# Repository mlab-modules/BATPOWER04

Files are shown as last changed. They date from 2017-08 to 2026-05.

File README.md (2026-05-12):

# BATPOWER04 - Step-down Voltage Converter Module

BATPOWER04 is a step-down voltage converter module based on the [LM3485](doc/pdf/lm3485.pdf) PFET buck controller. The input voltage range is 4.5 V to 16 V. The output voltage can be selected by jumpers as 3.3 V or 5 V, or configured as a custom voltage using an external resistor or trimmer. The output voltage range is 0.25 V to Vin.

The module is especially suited for battery-powered applications, but it can also be used as a step-down converter from an external 12 V supply to 3.3 V or 5 V for MLAB designs. Its key feature is high efficiency, up to 93%, which helps reduce waste heat.

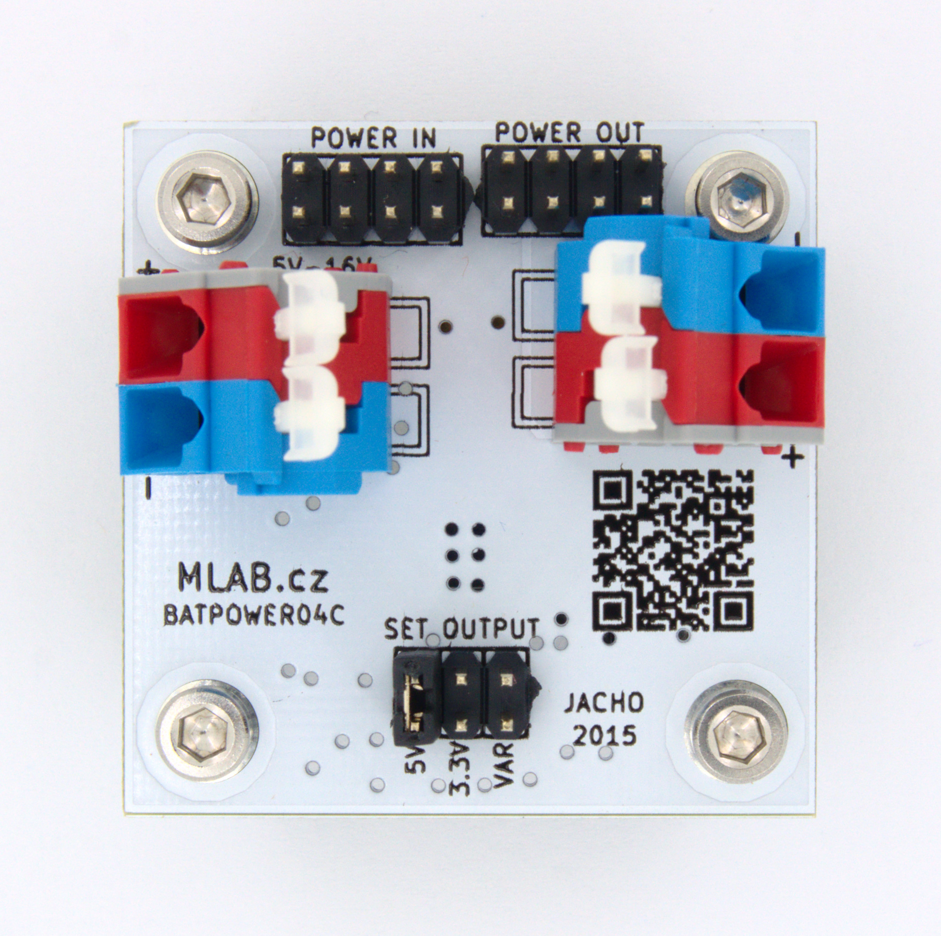
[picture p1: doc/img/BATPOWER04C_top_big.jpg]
BATPOWER04 module


| Parameter | Value | Description |
|---|---|---|
| Step-down controller | [LM3485](doc/pdf/lm3485.pdf) | PFET Buck controller |
| Vin | 4.5 V - 16 V | Input voltage range |
| Vout | 0.25 V - Vin | 3.3 V or 5 V selectable by jumper. Other values require an external resistor or trimmer. |

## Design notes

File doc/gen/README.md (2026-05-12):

# PCB

Board size: 40.13x40.13 mm (1.58x1.58 inches)

- This is the size of the rectangle that contains the board
- Thickness: 1.6 mm (63 mils)
- Material: FR4
- Finish: HAL
- Layers: 2
- Copper thickness: 35 µm

Solder mask: TOP / BOTTOM

- Color: Green

Silk screen: TOP / BOTTOM

- Color: White

# Important sizes

Clearance: 0.2 mm (8 mils)

Track width: 0.25 mm (10 mils)

- By design rules: 0.0 mm (0 mils)

Drill: 0.75 mm (30 mils)

- Vias: 0.75 mm (30 mils) [Design: 0.4 mm (16 mils)]
- Pads: 1.0 mm (39 mils)
- The above values are real drill sizes, they add 0.1 mm (4 mils) to plated holes (PTH)

Via: 0.89/0.64 mm (35/25 mils)

- By design rules: 0.5/0.3 mm (20/12 mils)
- Micro via: yes [0.2/0.1 mm (8/4 mils)]
- Buried/blind via: yes
- Total: 35 (thru: 35 buried/blind: 0 micro: 0)

Outer Annular Ring: 0.07 mm (3 mils)

- By design rules: 0.33 mm (13 mils)

Eurocircuits class: 10A
- Using min drill 0.75 mm for an OAR of 0.07 mm

# General stats

Components count: (SMD/THT)

- Top: 0/14 (THT)
- Bottom: 15/2 (SMD + THT)

Defined tracks:

Used tracks:

- 0.25 mm (10 mils) (77) defined: no
- 0.3 mm (12 mils) (19) defined: no
- 0.4 mm (16 mils) (42) defined: no
- 1.0 mm (39 mils) (12) defined: no

Defined vias:

Used vias:

- 0.89/0.64 mm (35/25 mils) (Count: 35, Aspect: 1.8 A) defined: no

Holes (excluding vias):

- 0.9 mm (35 mils) (22)
- 1.3 mm (51 mils) (8)
- 3.0 mm (118 mils) (4)

Oval holes:

Drill tools (including vias and computing adjusts and rounding):

- 0.75 mm (30 mils) (35)
- 1.0 mm (39 mils) (22)
- 1.4 mm (55 mils) (8)
- 3.1 mm (122 mils) (4)

Solder paste stats:

Using a paste with 87.75 % alloy, that has an specific gravity for the alloy of 7.4 g/cm³
and 1.0 g/cm³ for the flux. This paste has an specific gravity of  4.15 g/cm³.

The stencil thickness is  0.12 mm.

| Side | Pads with paste | Area [mm²] | Paste [g] |
|---|---|---|---|
| Total  | 46 | 124.73 | 0.62 |

Note: this is just an approximation to the theoretical value. Margins of the solder mask and waste aren't computed.

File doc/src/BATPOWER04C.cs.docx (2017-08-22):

Snižující měnič

Jan Chroust

## Snižující měnič pro vstupní napětí 5 V – 16 V. Výstupní napětí přepínatelné na 5 V, 3,3 V a třetí rozsah je určen pro připojení potenciometru.

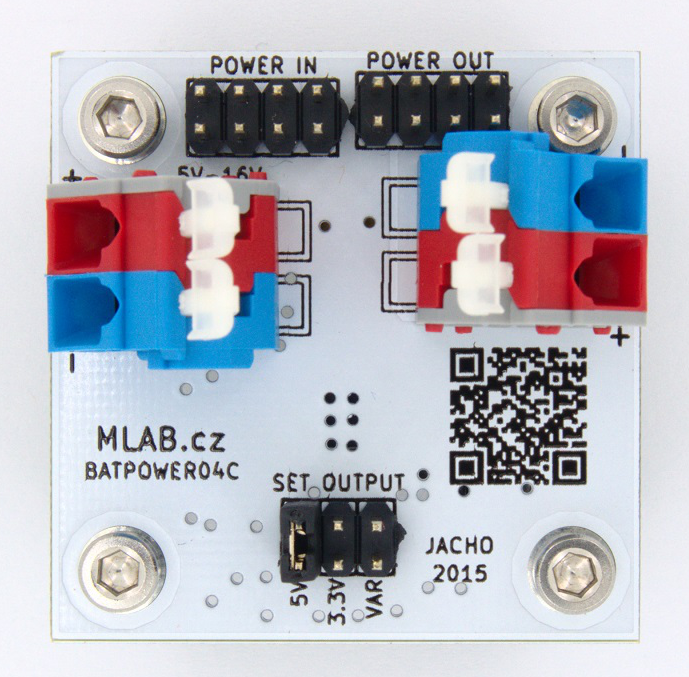
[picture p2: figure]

# 1. Technické parametry

Parametr | Hodnota | Poznámka
Integrovaný obvod | LM3485
Napájení | 5 V – 16 V | Omezeno kondenzátory
Rozměry | 40.13 x 40.13 x 16 mm | Výška nad základní deskou

# 2. Popis konstrukce

## 2.1. Úvodem

Modul je založen na integrovaném obvodu LM3485. Jedná se o snižující měnič se vstupním napětím v rozsahu 5 V – 16 V. Výstupní napětí je možné nastavit na 5 V, 3,3 V. Třetí rozsah je připraven pro připojení potenciometru.

Modul je možné osadit kombinací součástek, které by následně umožňovali snižovat vstupní napětí v rozsahu 5 V – 35 V. Pro jinou hodnotu napětí na výstupu je možné si vypočítat jiný poměr odporů na zpětné vazbě měniče.

Vzorec:

V_(out) =1,242*(R_3 +R_(5,2,4) )/R_(5,2,4)

R_(5,2,4) =(1,242*R_3)/(V_(OUT) -1,242)

## 2.2. Schéma

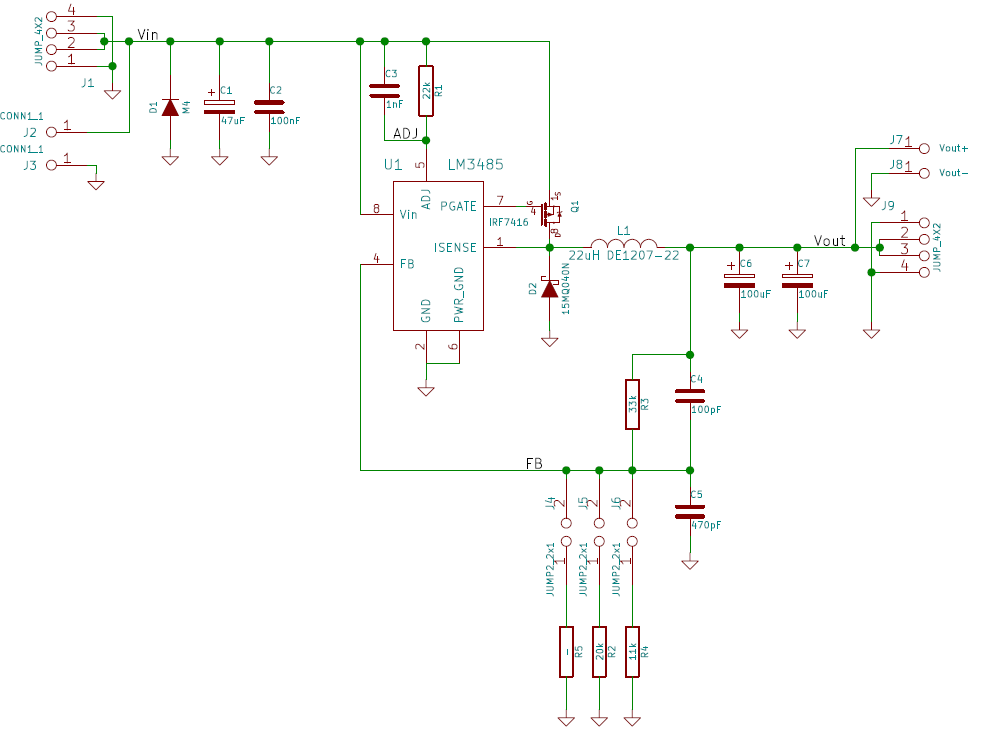
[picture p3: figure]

# 3. Osazení a oživení

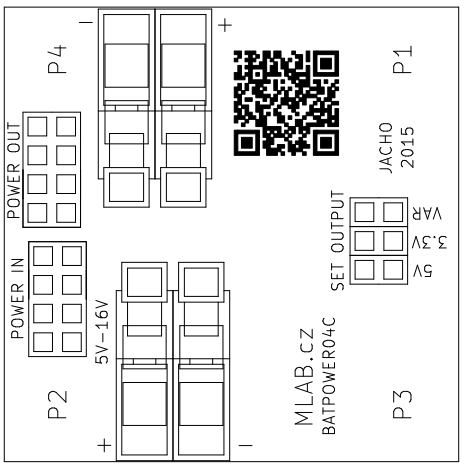
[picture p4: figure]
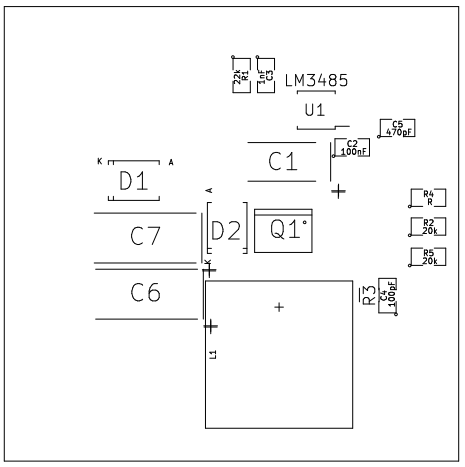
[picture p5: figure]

## 3.1. Osazení

Označení | Množství | Hodnota | Pouzdro
C1 | 1 | 47uF | TantalC_SizeC_Reflow
C2 | 1 | 100nF | SMD-0805
C3 | 1 | 1nF | SMD-0805
C4 | 1 | 100pF | SMD-0805
C5 | 1 | 470pF | SMD-0805
C6,C7 | 2 | 100uF | TantalC_SizeD_Reflow
D1 | 1 | M4 | Diode-SMA_Standard
D2 | 1 | 15MQ040N | Diode-SMA_Standard
J1,J9 | 2 | JUMP_4X2 | Pin_Header_Straight_2x04
J3,J7,J2,J8 | 4 | Wago256 | WAGO256
J4,J5,J6 | 3 | JUMP_2x1 | Pin_Header_Straight_1x02
L1 | 1 | 22uH | DE1207-22
P1,P2,P3,P4 | 4 | Sroub M3 | MountingHole_3mm
Q1 | 1 | IRF7416 | SO-8
R1 | 1 | 22k | SMD-0805
R2 | 1 | 20k | SMD-0805
R3 | 1 | 33k | R_0805
R4 | 1 | 11k | R_0805
R5 | 1 | neosazen | SMD-0805
U1 | 1 | LM3485 | MSOP-8_3x3mm

Jumper: pozice 3,3 V

BATPOWER04C / 2016-09-14 / jacho/ http://www.mlab.cz 2 / 3

BATPOWER04C MLAB

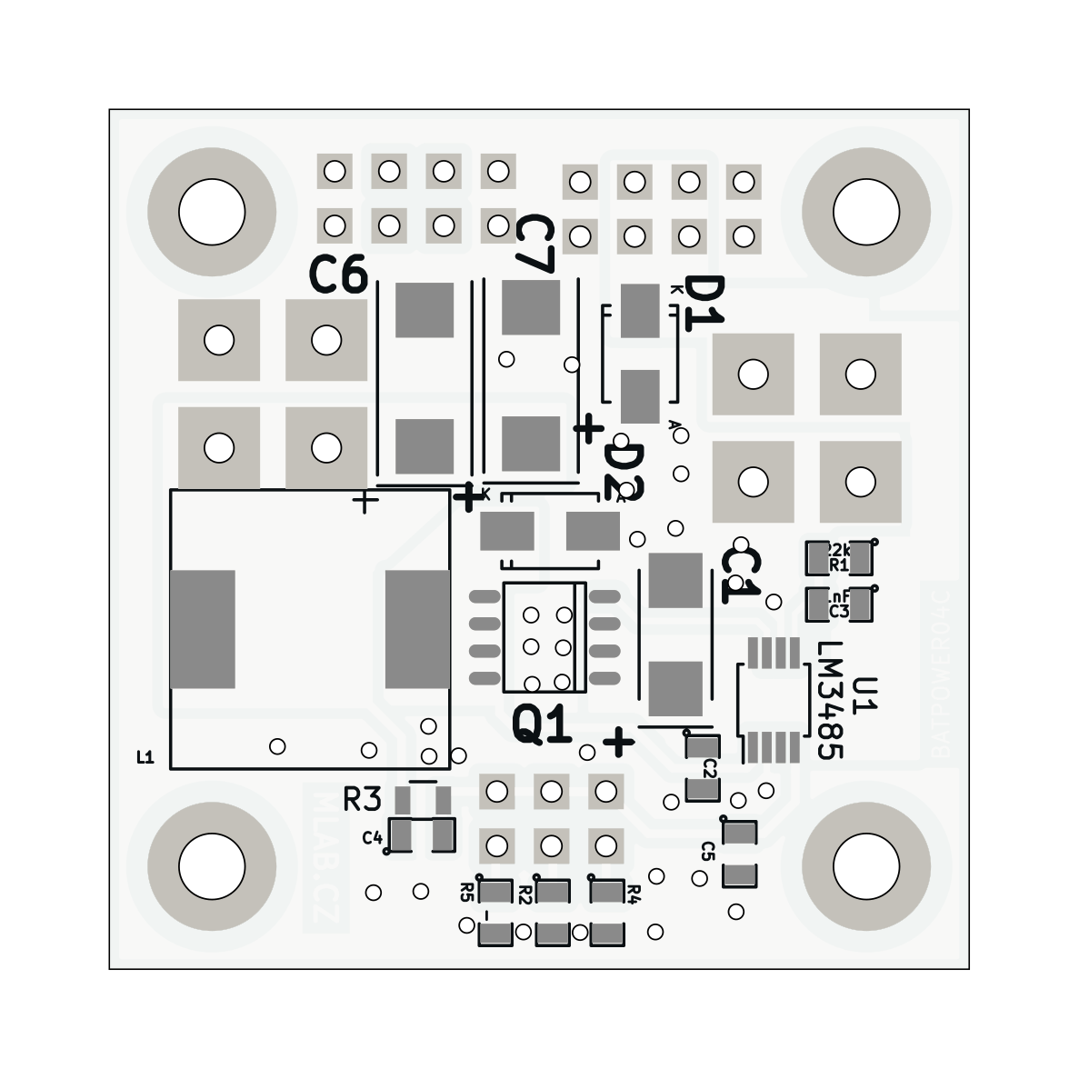
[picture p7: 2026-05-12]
doc/gen/img/BATPOWER04-bottom.png

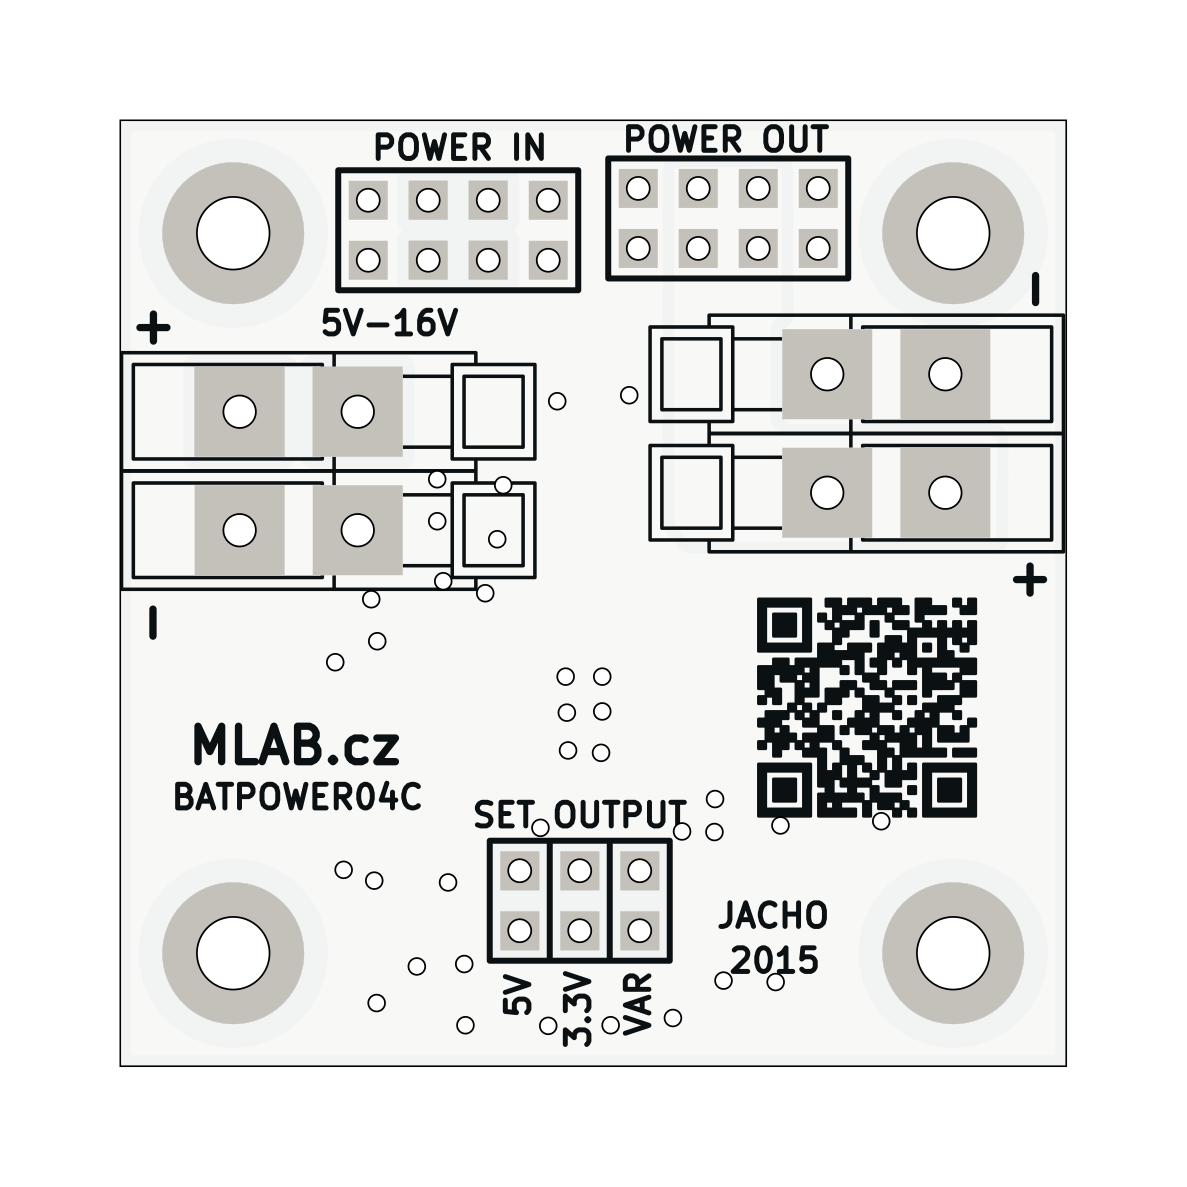
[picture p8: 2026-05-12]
doc/gen/img/BATPOWER04-top.png

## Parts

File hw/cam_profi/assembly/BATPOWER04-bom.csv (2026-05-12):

Component | Description | Part | References | Value | Footprint | Quantity Per PCB | Datasheet
1 |  | C_7 | C4 | 100pF | SMD-0805 | 1
2 |  | C_8 | C5 | 470pF | SMD-0805 | 1
3 |  | C_5 | C3 | 1nF | SMD-0805 | 1
4 |  | C_6 | C2 | 100nF | SMD-0805 | 1
5 |  | CP2_4 | C1 | 47uF | TantalC_SizeC_Reflow | 1
6 |  | CP2_5 | C6 | 100uF | TantalC_SizeD_Reflow | 1
7 |  | CP2_6 | C7 | 100uF | TantalC_SizeD_Reflow | 1
8 |  | DIODESCH_2 | D2 | 15MQ040N | Diode-SMA_Standard | 1
9 |  | DIODE_2 | D1 | M4 | Diode-SMA_Standard | 1
10 |  | CONN1_1_5 | J2 | CONN1_1 | WAGO256 | 1
11 |  | CONN1_1_6 | J3 | CONN1_1 | WAGO256 | 1
12 |  | JUMP2_2x1_4 | J4 | JUMP2_2x1 | Pin_Header_Straight_1x02 | 1
13 |  | JUMP2_2x1_5 | J5 | JUMP2_2x1 | Pin_Header_Straight_1x02 | 1
14 |  | JUMP2_2x1_6 | J6 | JUMP2_2x1 | Pin_Header_Straight_1x02 | 1
15 |  | JUMP_4X2_3 | J1 | JUMP_4X2 | Pin_Header_Straight_2x04 | 1
16 |  | JUMP_4X2_4 | J9 | JUMP_4X2 | Pin_Header_Straight_2x04 | 1
17 |  | CONN1_1_8 | J7 | Vout+ | WAGO256 | 1
18 |  | CONN1_1_7 | J8 | Vout- | WAGO256 | 1
19 |  | INDUCTOR_SMALL_2 | L1 | 22uH DE1207-22 | DE1205-10 | 1
20 |  | IRF7416_2 | Q1 | IRF7416 | SO-8 | 1
21 | Resistor | R | R4 | 11k | SMD-0805 | 1 | ~
22 | Resistor | R | R2 | 20k | SMD-0805 | 1 | ~
23 | Resistor | R | R1 | 22k | SMD-0805 | 1 | ~
24 | Resistor | R | R3 | 33k | SMD-0805 | 1 | ~
25 | Resistor | R | R5 | - | SMD-0805 | 1 | ~
26 |  | LM3485_2 | U1 | LM3485 | MSOP-8_3x3mm_Pitch0.65mm | 1

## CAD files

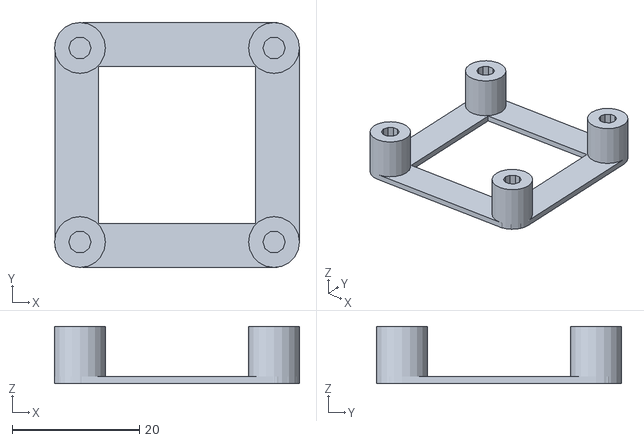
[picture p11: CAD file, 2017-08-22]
cad/4x4MLAB_frame.stl
38.5 x 38.5 x 9.00

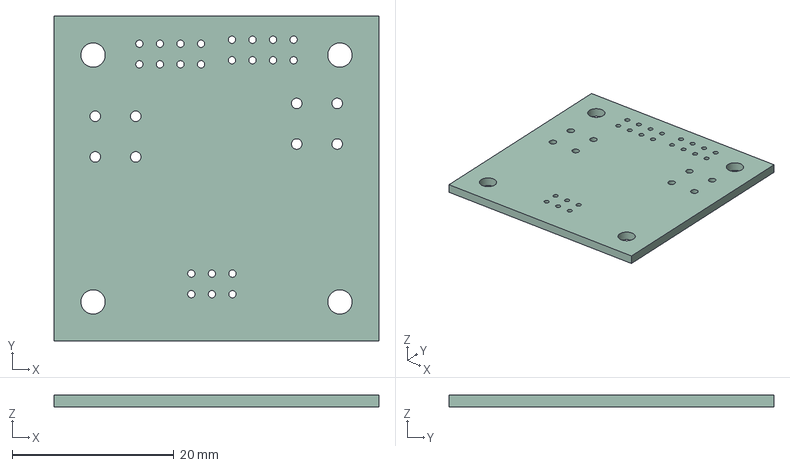
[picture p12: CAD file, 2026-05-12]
doc/gen/BATPOWER04.step
40.1 x 40.1 x 1.51 mm

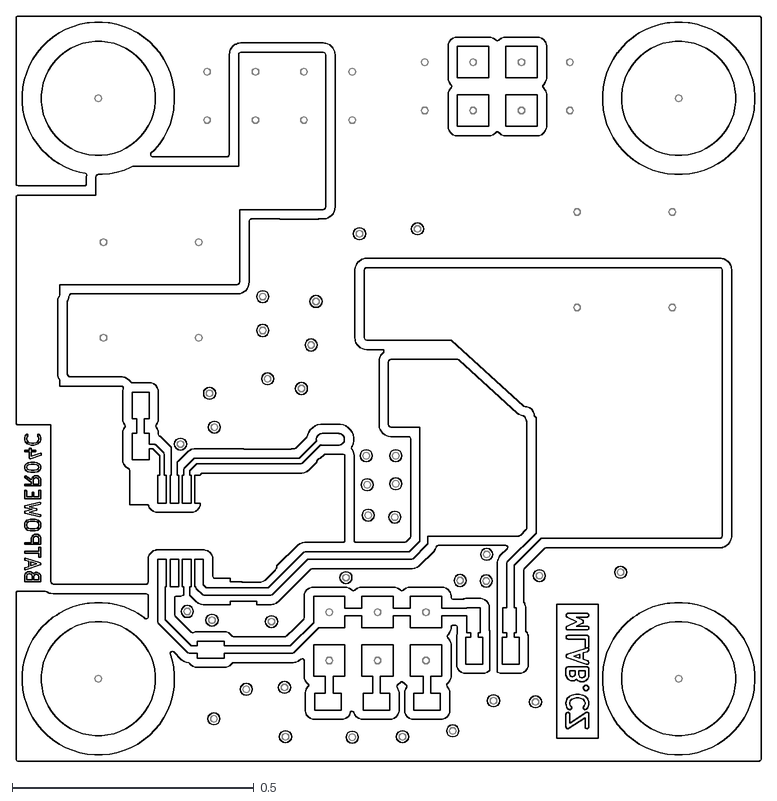
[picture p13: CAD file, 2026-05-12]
doc/gen/dxf/BATPOWER04-B_Cu.dxf
1.54 x 1.54

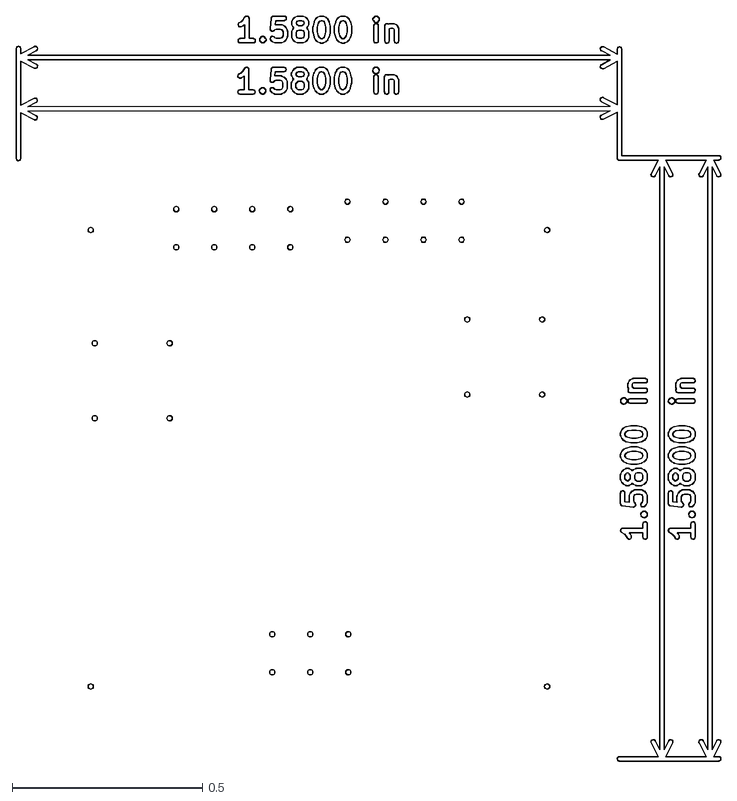
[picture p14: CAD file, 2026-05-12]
doc/gen/dxf/BATPOWER04-User_Drawings.dxf
1.85 x 1.96

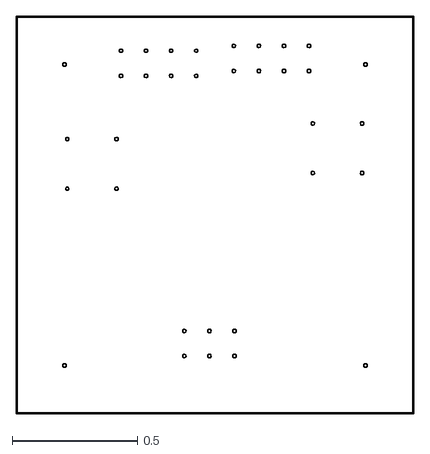
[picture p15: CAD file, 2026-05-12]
doc/gen/dxf/BATPOWER04-Edge_Cuts.dxf
1.58 x 1.58

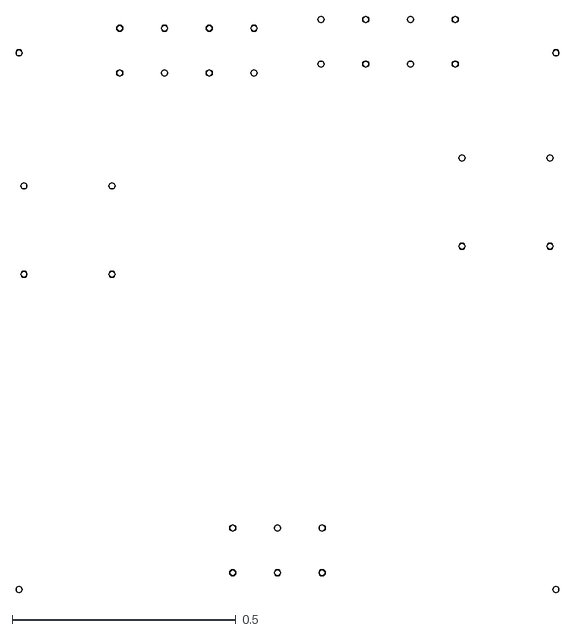
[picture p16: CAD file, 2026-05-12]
doc/gen/dxf/BATPOWER04-F_Courtyard.dxf
1.21 x 1.29

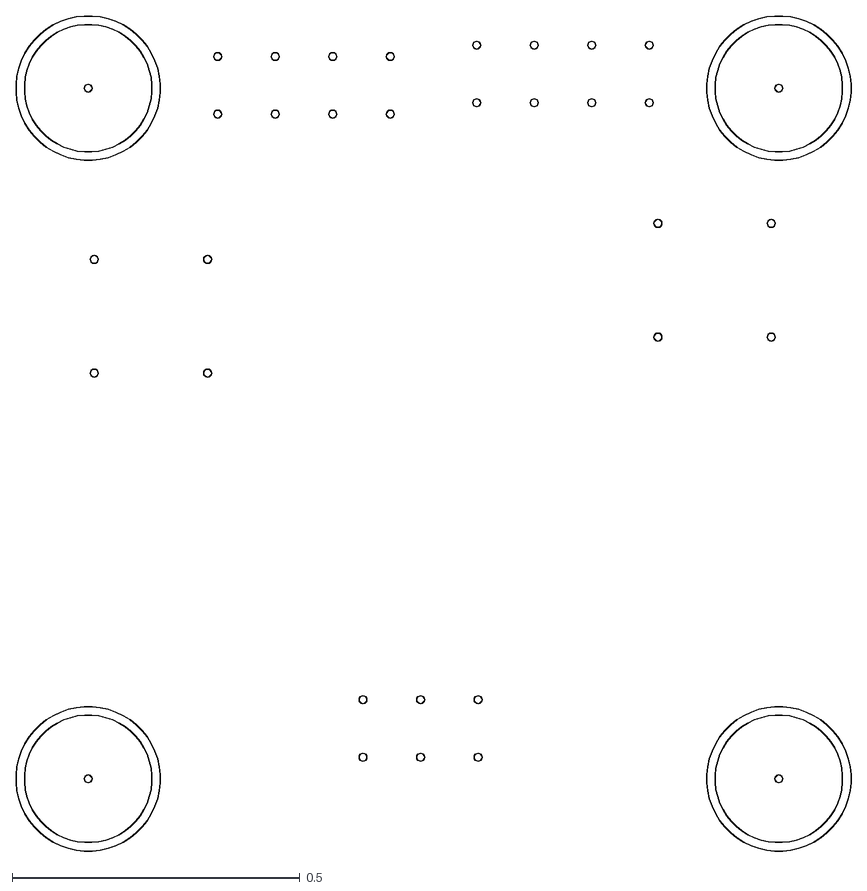
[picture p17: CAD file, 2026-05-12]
doc/gen/dxf/BATPOWER04-User_Comments.dxf
1.45 x 1.45

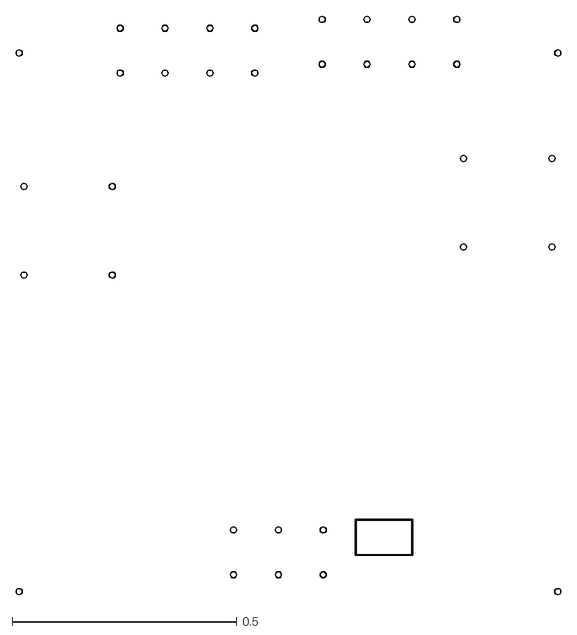
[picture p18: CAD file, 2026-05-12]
doc/gen/dxf/BATPOWER04-B_Courtyard.dxf
1.21 x 1.29

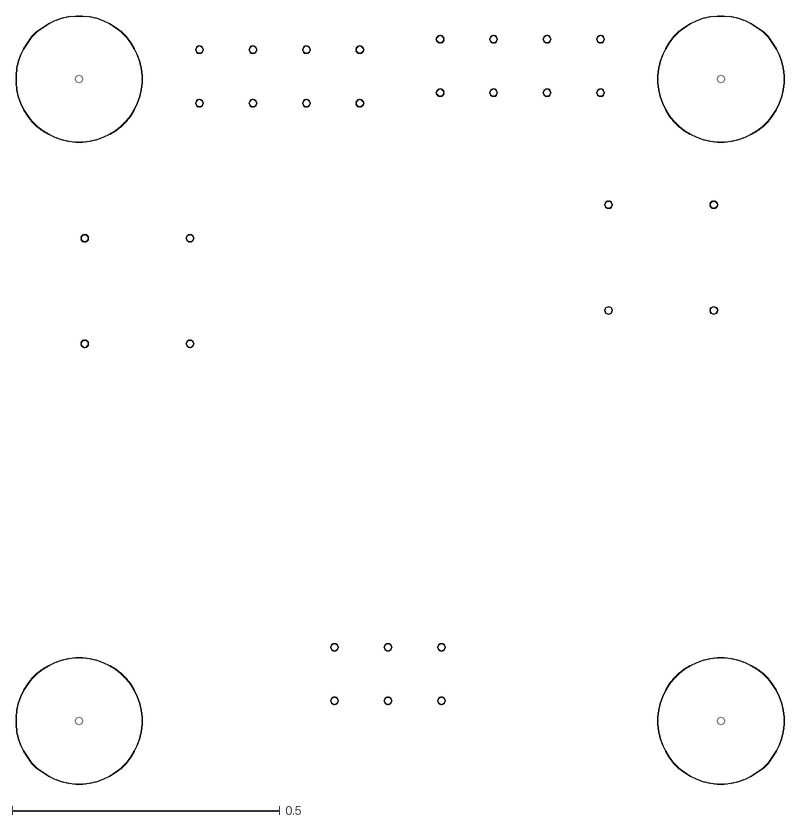
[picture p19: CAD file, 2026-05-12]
doc/gen/dxf/BATPOWER04-F_Adhesive.dxf
1.44 x 1.44

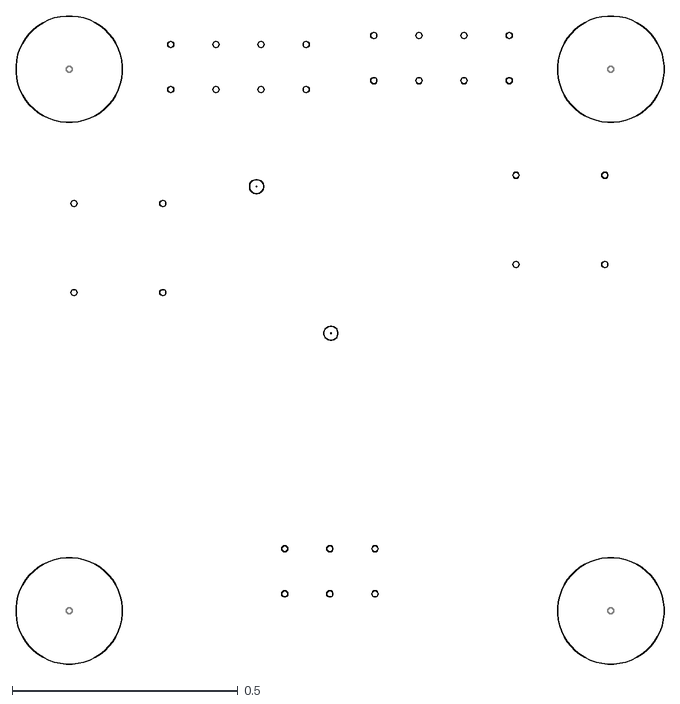
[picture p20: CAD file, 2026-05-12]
doc/gen/dxf/BATPOWER04-B_Adhesive.dxf
1.44 x 1.44

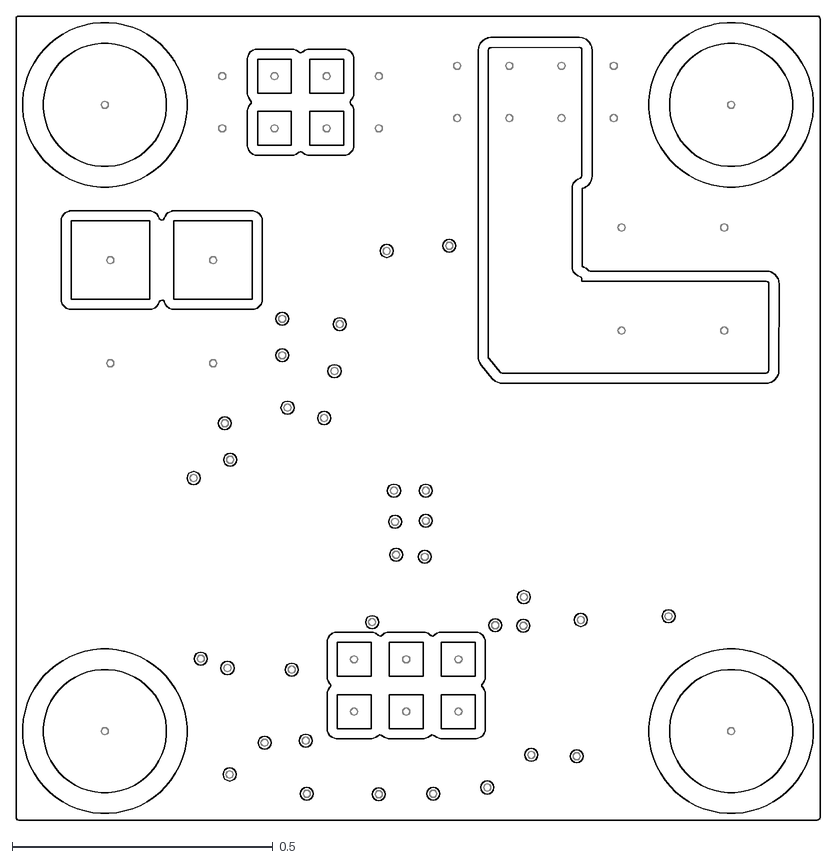
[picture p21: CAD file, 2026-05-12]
doc/gen/dxf/BATPOWER04-F_Cu.dxf
1.54 x 1.54

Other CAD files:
cad/src/4x4MLAB_frame.scad
cad/4x4MLAB_frame.amf
doc/gen/dxf/BATPOWER04-B_Mask.dxf
doc/gen/dxf/BATPOWER04-B_Paste.dxf
doc/gen/dxf/BATPOWER04-B_Silkscreen.dxf
doc/gen/dxf/BATPOWER04-F_Mask.dxf
doc/gen/dxf/BATPOWER04-F_Paste.dxf
doc/gen/dxf/BATPOWER04-F_Silkscreen.dxf

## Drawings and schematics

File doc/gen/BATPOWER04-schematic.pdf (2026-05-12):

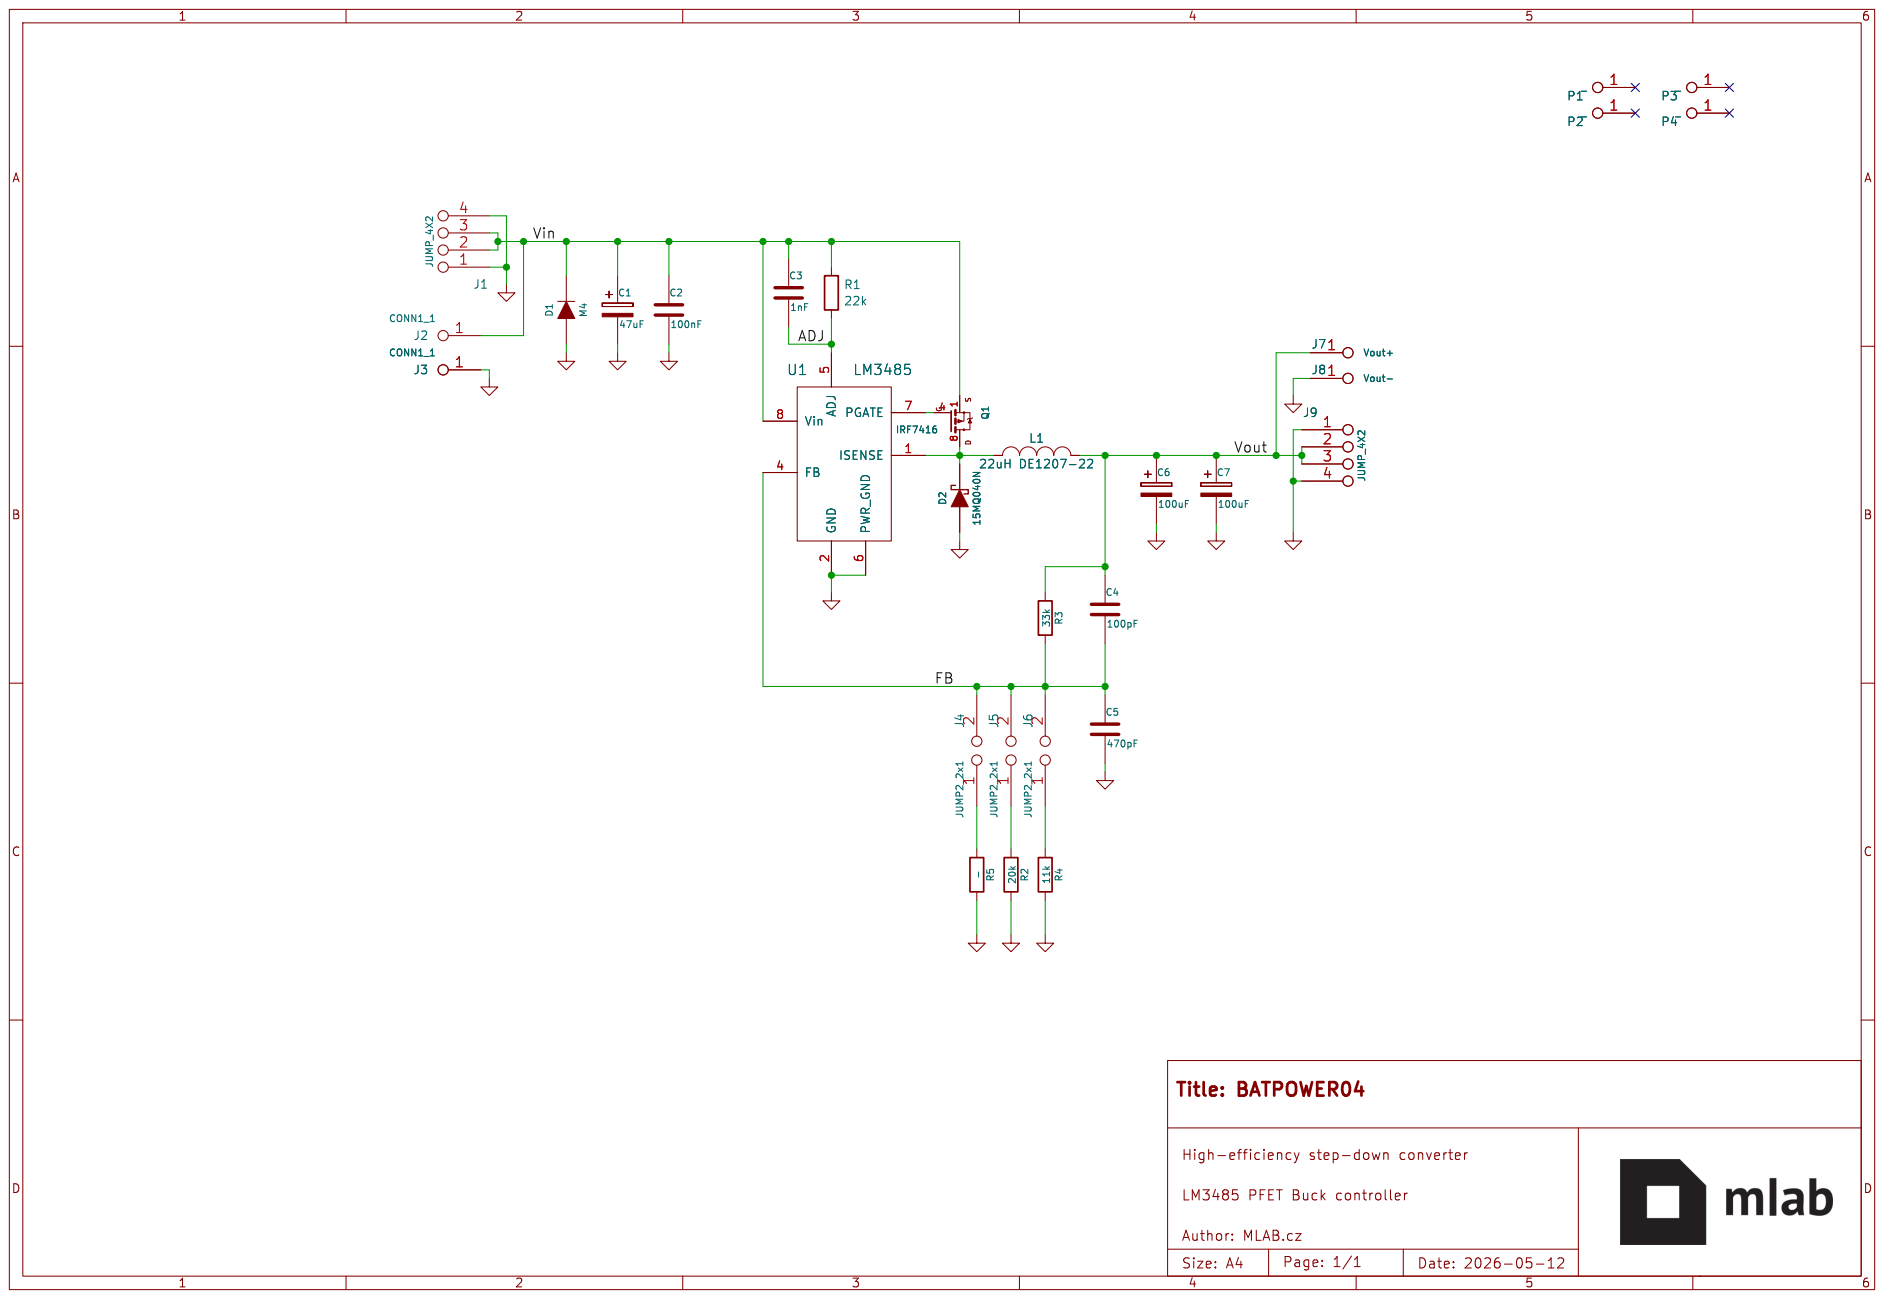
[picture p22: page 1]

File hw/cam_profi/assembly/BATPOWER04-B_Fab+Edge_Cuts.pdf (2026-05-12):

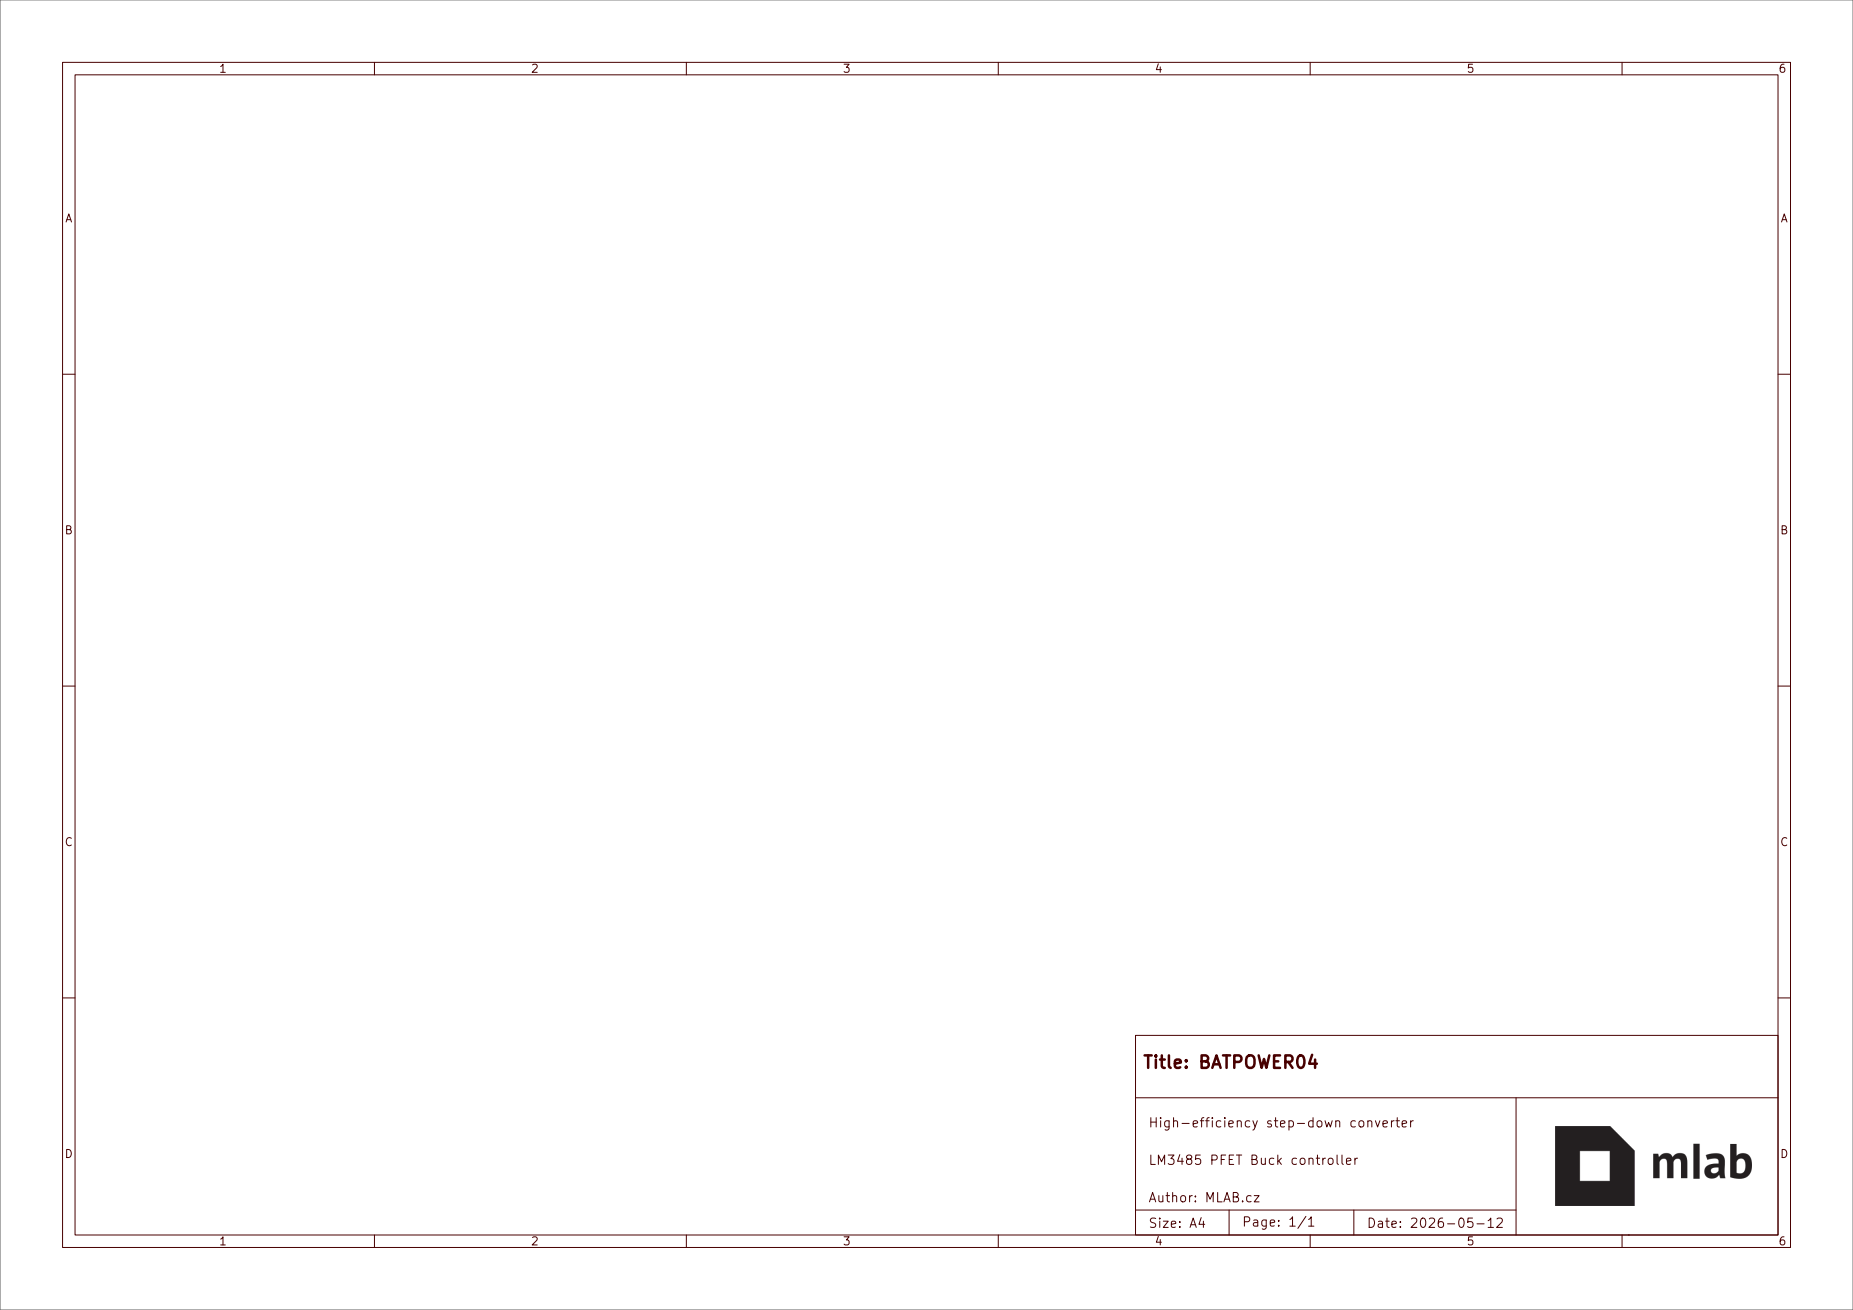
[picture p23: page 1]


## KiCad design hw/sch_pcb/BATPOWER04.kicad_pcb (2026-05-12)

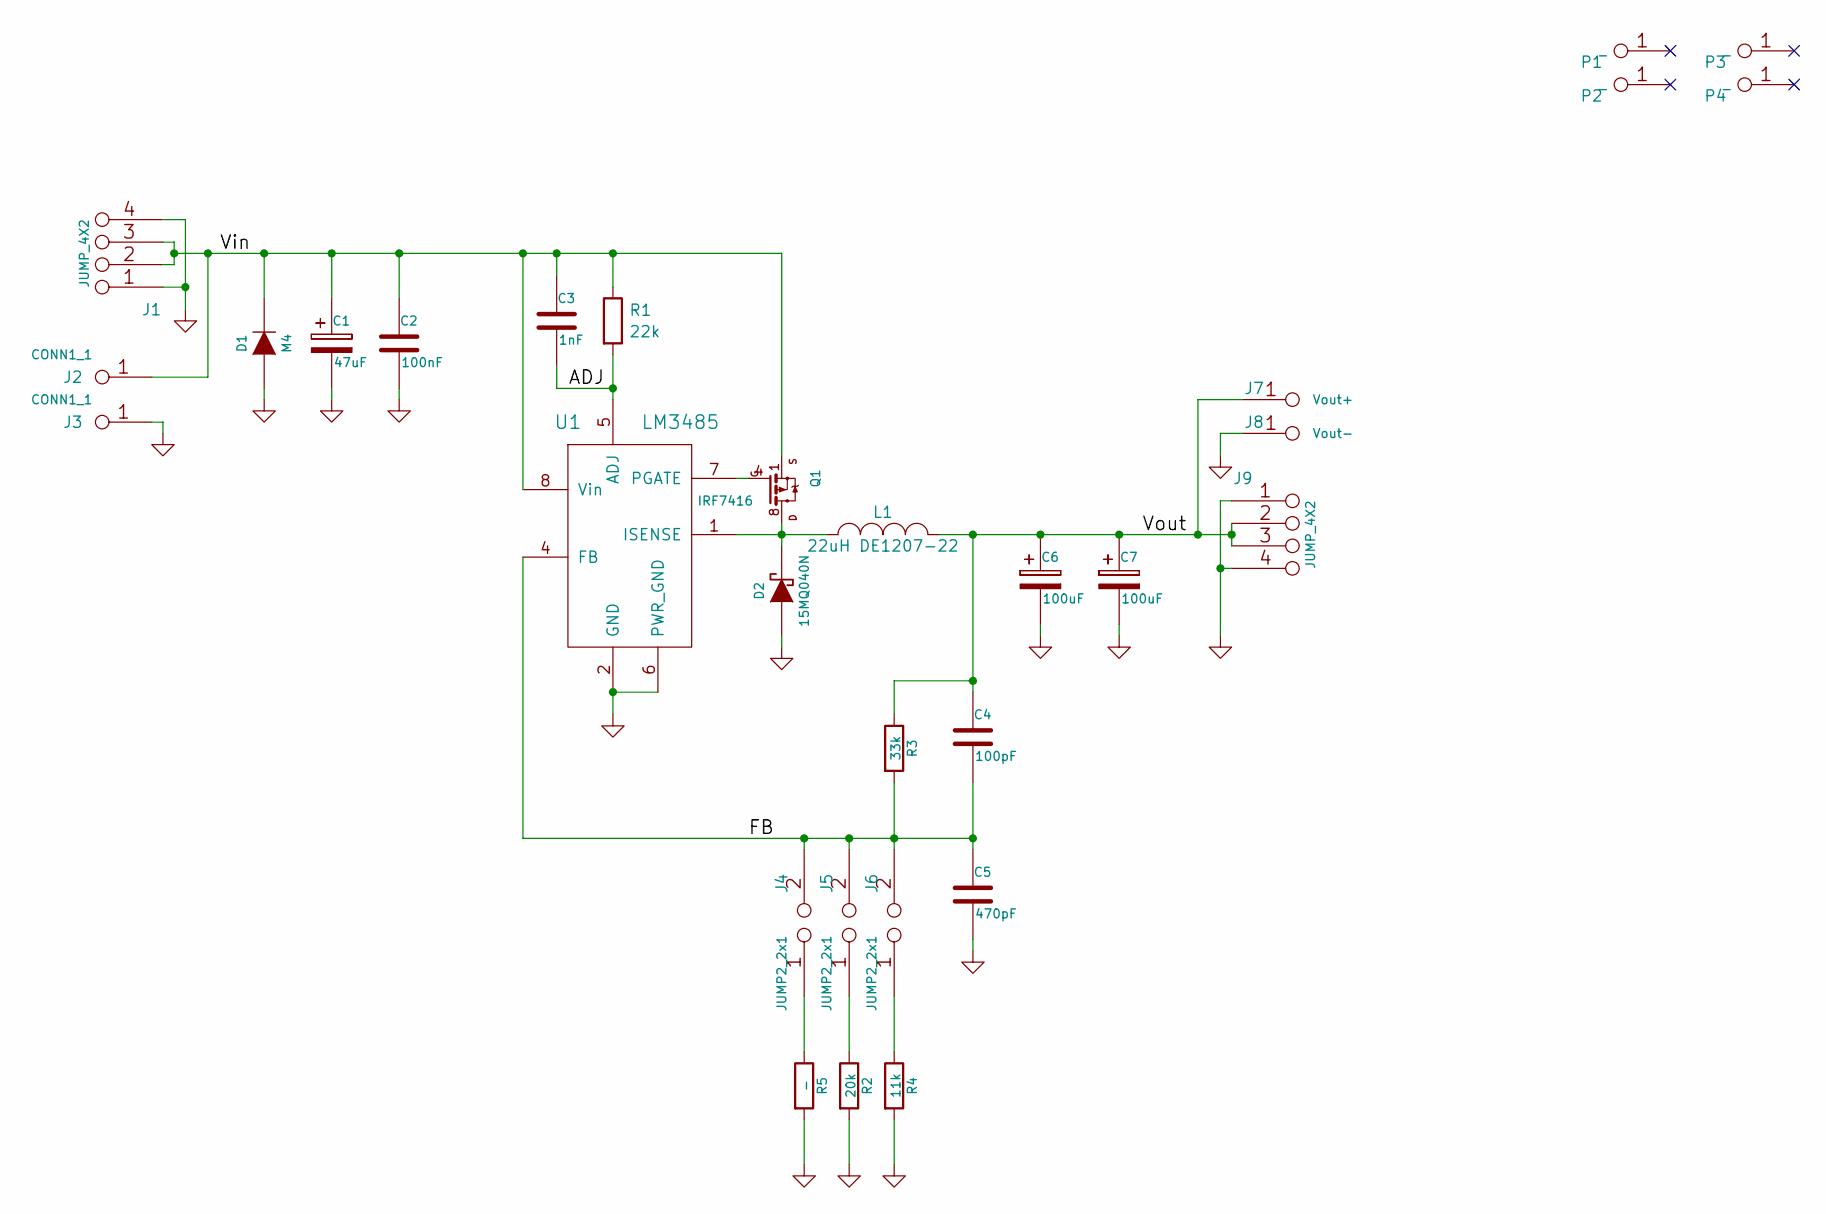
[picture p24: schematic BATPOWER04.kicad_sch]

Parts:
C1: 47uF; TantalC_SizeC_Reflow
C2: 100nF; SMD-0805
C3: 1nF; SMD-0805
C4: 100pF; SMD-0805
C5: 470pF; SMD-0805
C6, C7: 100uF; TantalC_SizeD_Reflow
D1: M4; Diode-SMA_Standard
D2: 15MQ040N; Diode-SMA_Standard
J1, J9: JUMP_4X2; Pin_Header_Straight_2x04
J2, J3: CONN1_1; WAGO256
J4, J5, J6: JUMP2_2x1; Pin_Header_Straight_1x02
J7: Vout+; WAGO256
J8: Vout-; WAGO256
L1: 22uH DE1207-22; DE1205-10
P1, P2, P3, P4: _; MountingHole_3mm
Q1: IRF7416; SO-8
R1: 22k; SMD-0805
R2: 20k; SMD-0805
R3: 33k; SMD-0805
R4: 11k; SMD-0805
R5: -; SMD-0805
U1: LM3485; MSOP-8_3x3mm_Pitch0.65mm

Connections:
/ADJ: C3.2, R1.2, U1.5 (ADJ)
/FB: C4.2, C5.1, J4.2, J5.2, J6.2, R3.2, U1.4 (FB)
/Vin: C1.1, C2.1, C3.1, D1.2 (K), J1.2, J1.3, J1.6, J1.7, J2.1, Q1.1 (S), Q1.2 (S), Q1.3 (S), R1.1, U1.8 (Vin)
/Vout: C4.1, C6.1, C7.1, J7.1, J9.2, J9.3, J9.6, J9.7, L1.2, R3.1
GND: C1.2, C2.2, C5.2, C6.2, C7.2, D1.1 (A), D2.1 (A), J1.1, J1.4, J1.5, J1.8, J3.1, J8.1, J9.1, J9.4, J9.5, J9.8, R2.2, R4.2, R5.2, U1.2 (GND), U1.6 (PWR_GND)
unnamed: D2.2 (K), L1.1, Q1.5 (D), Q1.6 (D), Q1.7 (D), Q1.8 (D), U1.1 (ISENSE)
unnamed: J4.1, R5.1
unnamed: J5.1, R2.1
unnamed: J6.1, R4.1
unnamed: Q1.4 (G), U1.7 (PGATE)

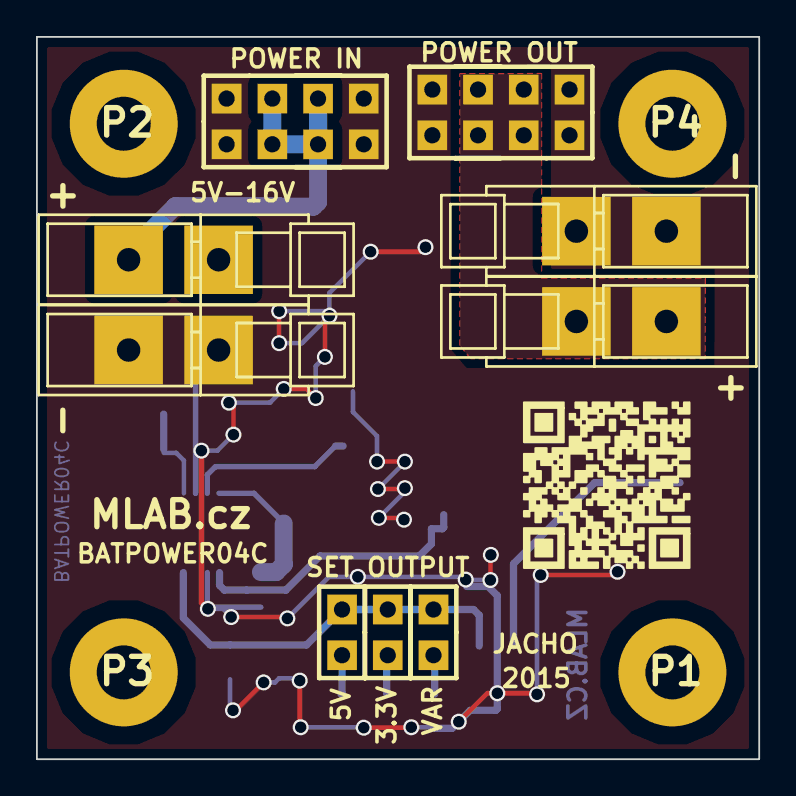
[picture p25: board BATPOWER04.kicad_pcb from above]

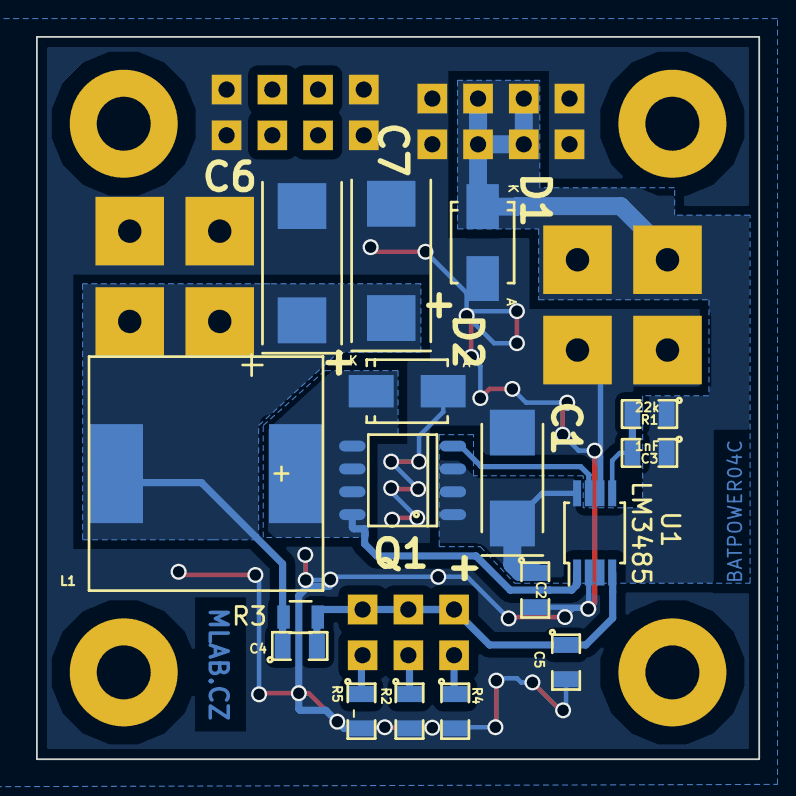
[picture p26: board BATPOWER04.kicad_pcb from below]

Board: 2 copper layers, 40.1 x 40.1 mm, 30 parts (17 on the bottom side), 10 nets.

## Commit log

2017-08-22 rename category folders
    [4x4MLAB_frame.amf, 4x4MLAB_frame.scad, 4x4MLAB_frame.stl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]
2017-08-22 rename files and module folders
    [4x4MLAB_frame.amf, 4x4MLAB_frame.scad, 4x4MLAB_frame.stl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]
2017-08-22 create hw folder
    [BATPOWER04C.kicad_pcb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]
2022-04-06 Update actions products
    [BATPOWER04C-B_Cu.gbr, BATPOWER04C-B_Mask.gbr, BATPOWER04C-Edge_Cuts.gbr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]
2026-05-12 Update project to KiCADv9.
    [BATPOWER04.kicad_pcb, BATPOWER04.kicad_sch, BATPOWER04C.kicad_pcb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]
2026-05-12 Automatic update of KiCAD outputs
    [BATPOWER04-B_Adhesive.dxf, BATPOWER04-B_Courtyard.dxf, BATPOWER04-B_Cu.dxf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]
